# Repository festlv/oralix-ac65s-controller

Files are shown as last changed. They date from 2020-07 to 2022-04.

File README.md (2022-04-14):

# Misc. tools for Gendex Oralix AC65s control

Schematics is a bit stale- initially it was drawn for Arduino Nano, but couldn't find one, 
so a random ESP32 based module was used instead (which was not a bad idea because WiFi provides
better galvanic isolation than shady circuit wired up on perfboard).

ESP32 firmware is however stable- it was initially tested using 12VAC input to allow safe probing
of signals in order to verify the zero crossing detection and pulse timing accuracy.

Description of Gendex Oralix AC tube: https://nucwiki.org/wiki/index.php/Gendex_Oralix_AC

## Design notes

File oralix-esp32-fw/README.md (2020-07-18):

# Triac driver for Gendex Oralix AC65s

This repository contains firmware for ESP32 which controls a triac and allows 
firing X-Ray tube remotely via telnet (providing ultimate galvanic isolation).

Project is built against esp-idf v4.0.x

## Building and installing

    mkdir build && cd build
    cmake ..
    make -j8
    # make menuconfig if want to customize WiFi AP name
    make flash
    
## Usage

0. ESP32 will act as WiFi access point.
1. Connect to WiFi AP (AngryPhotons by default)
2. Use telnet client to connect to 192.168.4.1:23
3. Enter help to see the list of commands (arm, disarm, fire, warmup)

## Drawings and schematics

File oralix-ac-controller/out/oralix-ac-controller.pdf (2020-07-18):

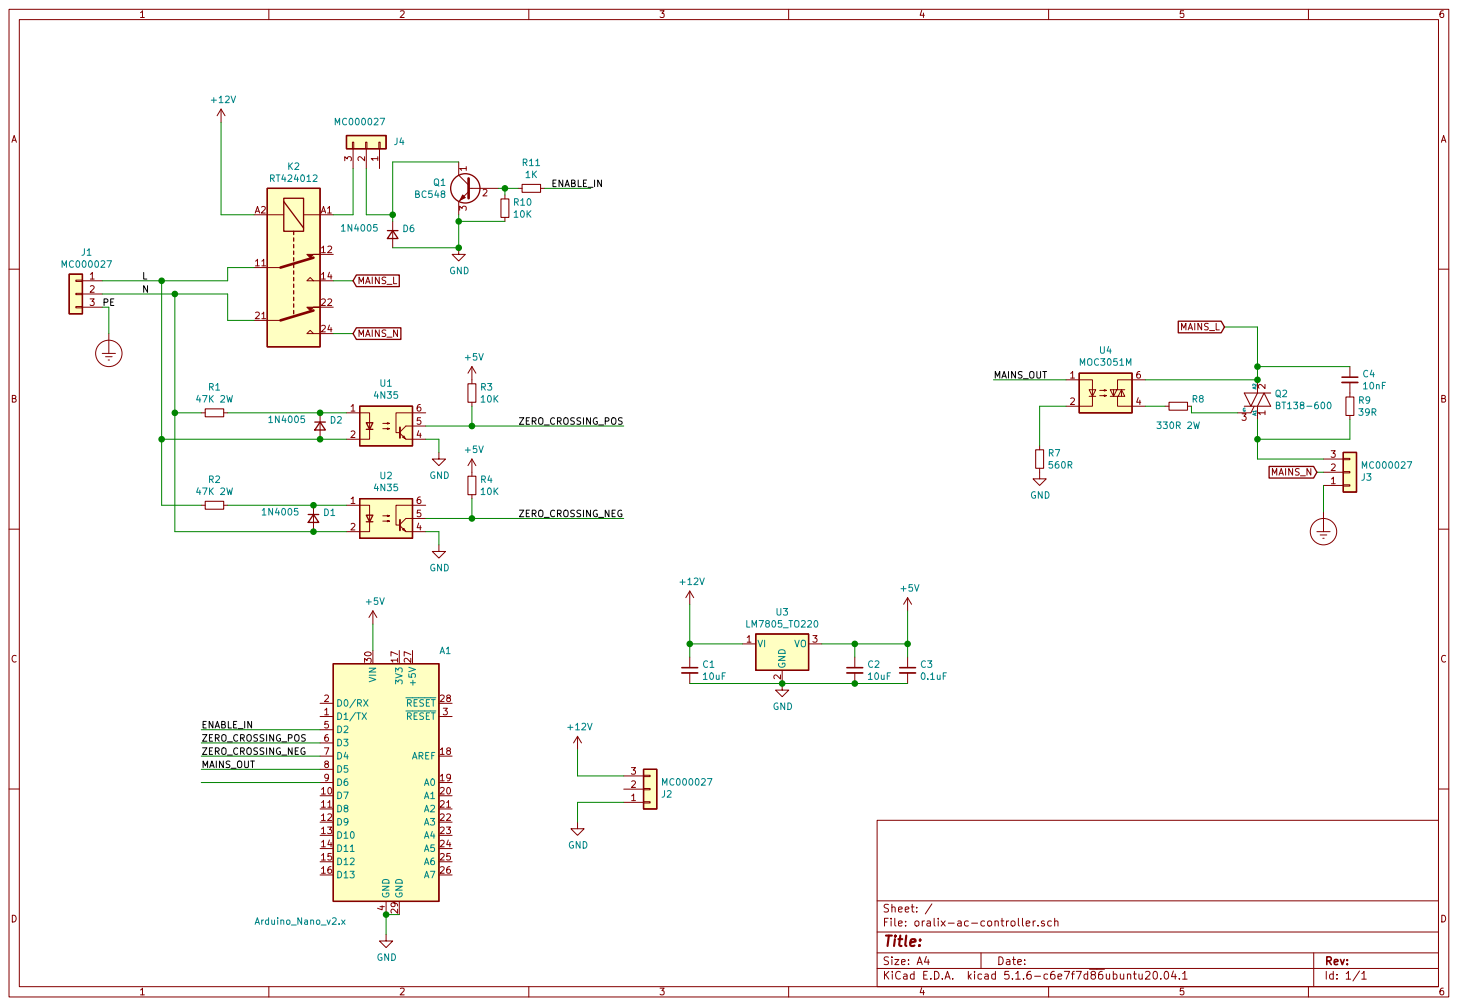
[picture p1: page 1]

Id: 1/1 Title: File: oralix-ac-controller.sch Sheet: /

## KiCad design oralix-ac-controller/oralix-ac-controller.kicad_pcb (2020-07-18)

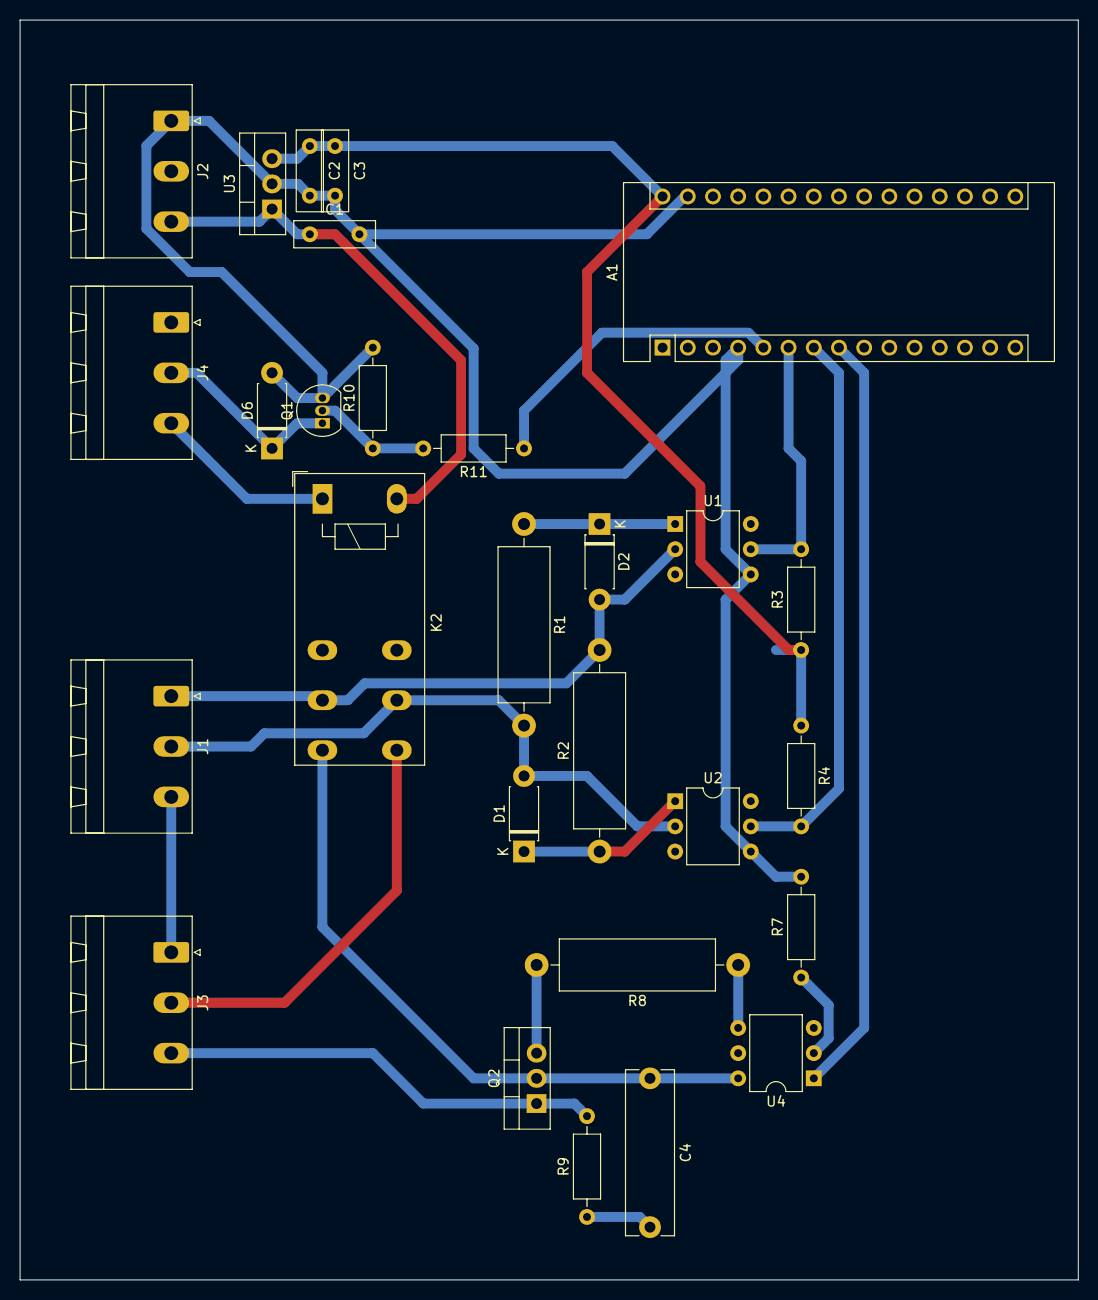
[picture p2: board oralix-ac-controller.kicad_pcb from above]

Board: 2 copper layers, 106.7 x 127.0 mm, 28 parts (0 on the bottom side), 22 nets.

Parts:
A1: Arduino_Nano_v2.x; Arduino_Nano
C1, C2: 10uF; C_Disc_D8.0mm_W2.5mm_P5.00mm
C3: 0.1uF; C_Disc_D8.0mm_W2.5mm_P5.00mm
C4: 10nF; C_Rect_L16.5mm_W4.7mm_P15.00mm_MKT
D1, D2, D6: 1N4005; D_DO-41_SOD81_P7.62mm_Horizontal
J1, J2, J3, J4: MC000027; PhoenixContact_MSTBA_2,5_3-G-5,08_1x03_P5.08mm_Horizontal
K2: RT424012; Relay_DPDT_Schrack-RT2-FormC_RM5mm
Q1: BC548; TO-92_Inline
Q2: BT138-600; TO-220-3_Vertical
R1, R2: 47K 2W; R_Axial_DIN0516_L15.5mm_D5.0mm_P20.32mm_Horizontal
R3, R4, R10: 10K; R_Axial_DIN0207_L6.3mm_D2.5mm_P10.16mm_Horizontal
R7: 560R; R_Axial_DIN0207_L6.3mm_D2.5mm_P10.16mm_Horizontal
R8: 330R 2W; R_Axial_DIN0516_L15.5mm_D5.0mm_P20.32mm_Horizontal
R9: 39R; R_Axial_DIN0207_L6.3mm_D2.5mm_P10.16mm_Horizontal
R11: 1K; R_Axial_DIN0207_L6.3mm_D2.5mm_P10.16mm_Horizontal
U1, U2: 4N35; DIP-6_W7.62mm
U3: LM7805_TO220; TO-220-3_Vertical
U4: MOC3051M; DIP-6_W7.62mm

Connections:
+5V: A1.30, C2.1, C3.1, R3.1, R4.1, U3.3
+12V: C1.1, J2.3, K2.A2, U3.1
/ENABLE_IN: A1.5, R11.1
/L: D2.2, J1.1, K2.11, R2.2, U1.2
/MAINS_OUT: A1.8, U4.1
/N: D1.2, J1.2, K2.21, R1.2, U2.2
/ZERO_CROSSING_NEG: A1.7, R4.2, U2.5
/ZERO_CROSSING_POS: A1.6, R3.2, U1.5
Earth_Protective: J1.3, J3.1
GND: A1.4, A1.29, C1.2, C2.2, C3.2, D6.2, J2.1, Q1.3, R7.2, R10.2, U1.4, U2.4, U3.2
MAINS_L: C4.1, K2.14, Q2.2, U4.6
MAINS_N: J3.2, K2.24
unnamed: C4.2, R9.1
unnamed: D1.1, R2.1, U2.1
unnamed: D2.1, R1.1, U1.1
unnamed: D6.1, J4.2, Q1.1
unnamed: J3.3, Q2.1, R9.2
unnamed: J4.3, K2.A1
unnamed: Q1.2, R10.1, R11.2
unnamed: Q2.3, R8.2
unnamed: R7.1, U4.2
unnamed: R8.1, U4.4

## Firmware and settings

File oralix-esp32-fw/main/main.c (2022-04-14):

/*  WiFi softAP Example

   This example code is in the Public Domain (or CC0 licensed, at your option.)

   Unless required by applicable law or agreed to in writing, this
   software is distributed on an "AS IS" BASIS, WITHOUT WARRANTIES OR
   CONDITIONS OF ANY KIND, either express or implied.
*/
#include <string.h>
#include "freertos/FreeRTOS.h"
#include "freertos/task.h"
#include "driver/uart.h"
#include "esp_system.h"
#include "esp_wifi.h"
#include "esp_event.h"
#include "esp_log.h"
#include "nvs_flash.h"
#include "telnet.h"
#include "lwip/err.h"
#include "lwip/sys.h"
#include "driver.h"
/* The examples use WiFi configuration that you can set via project configuration menu.

   If you'd rather not, just change the below entries to strings with
   the config you want - ie #define EXAMPLE_WIFI_SSID "mywifissid"
*/
#define EXAMPLE_ESP_WIFI_SSID      CONFIG_ESP_WIFI_SSID
#define EXAMPLE_ESP_WIFI_PASS      CONFIG_ESP_WIFI_PASSWORD
#define EXAMPLE_MAX_STA_CONN       CONFIG_ESP_MAX_STA_CONN

static const char *TAG = "wifi";

static void wifi_event_handler(void* arg, esp_event_base_t event_base,
                                    int32_t event_id, void* event_data)
{
    if (event_id == WIFI_EVENT_AP_STACONNECTED) {
        wifi_event_ap_staconnected_t* event = (wifi_event_ap_staconnected_t*) event_data;
        ESP_LOGI(TAG, "station "MACSTR" join, AID=%d",
                 MAC2STR(event->mac), event->aid);
    } else if (event_id == WIFI_EVENT_AP_STADISCONNECTED) {
        wifi_event_ap_stadisconnected_t* event = (wifi_event_ap_stadisconnected_t*) event_data;
        ESP_LOGI(TAG, "station "MACSTR" leave, AID=%d",
                 MAC2STR(event->mac), event->aid);
    }
}

static char tag[] = "xray";


#define STATIC_RESPOND(x) (respond_func((uint8_t*)x, strlen(x)))
#define RESPOND(x, y) (respond_func(x, y))

static void process_line(uint8_t *buffer, size_t size, void (*respond_func)(uint8_t*, size_t)) {
	ESP_LOGD(tag, "received: %.*s", size, buffer);

    if (strncmp((char*)buffer, "help", 4) == 0) {
        STATIC_RESPOND("Welcome brave warrior!\n");
        STATIC_RESPOND("Commands: \n");
        STATIC_RESPOND("status: driver status\n");
        STATIC_RESPOND("arm: arms the device (enables input relay)\n");
        STATIC_RESPOND("disarm: disarms\n");
        STATIC_RESPOND("warmup: warms up the tube (sends 6 pulses)\n");
        STATIC_RESPOND("fire <ms>: warms up the tube and performs an exposure of <ms> duration\n");
        STATIC_RESPOND("fire_nowarmup <ms>: fires tube for <ms> without warmup (CAUTION!)\n");
        STATIC_RESPOND("\n");
    }

    if (strncmp((char*)buffer, "status", 6) == 0) {
        char buf[256];
        uint32_t len = driver_get_status(buf, sizeof(buf));
        RESPOND((uint8_t *)buf, len);
    }

    if (strncmp((char*)buffer, "arm", 3) == 0) {
	    if (driver_arm()) {
	        STATIC_RESPOND("OK:armed\n");
	    } else {
	        STATIC_RESPOND("FAIL:failed to arm\n");
	    }
	}
    if (strncmp((char*)buffer, "disarm", 6) == 0) {
        if (driver_disarm()) {
            STATIC_RESPOND("OK:disarmed\n");
        } else {
            STATIC_RESPOND("FAIL:failed to disarm, run!\n");
        }
    }
    if (strncmp((char*)buffer, "warmup", 6) == 0) {
        if (driver_warmup()) {
            STATIC_RESPOND("OK:started warmup\n");
        } else {
            STATIC_RESPOND("FAIL:failed to start warmup!\n");
        }
    }
    if (strncmp((char*)buffer, "fire_nowarmup", 13) == 0) {
        int time_ms;
        if (sscanf((char*)(buffer + 14), "%d", &time_ms) == 1) {
            if (time_ms < 0 || time_ms > 3000) {
                STATIC_RESPOND("FAIL:Dave, I'm afraid I can't do that.\n");
            } else {
                if (driver_fire_time_nowarmup(time_ms)) {
                    STATIC_RESPOND("OK:firing!\n");
                } else {
                    STATIC_RESPOND("FAIL:failed to fire!\n");
                }
            }
        } else {
            STATIC_RESPOND("FAIL:failed to parse time!\n");
        }
    } else if (strncmp((char*)buffer, "fire", 4) == 0) {
        int time_ms;
        if (sscanf((char*)(buffer + 5), "%d", &time_ms) == 1) {
            if (time_ms < 0 || time_ms > 3000) {
                STATIC_RESPOND("FAIL:Dave, I'm afraid I can't do that.\n");
            } else {
                if (driver_fire_time(time_ms)) {
                    STATIC_RESPOND("OK:firing!\n");
                } else {
                    STATIC_RESPOND("FAIL:failed to fire!\n");
                }
            }
        } else {
            STATIC_RESPOND("FAIL:failed to parse time!\n");
        }
    }
}

static void telnetRecvData(uint8_t *buffer, size_t size) {
    process_line(buffer, size, &telnet_esp32_sendData);
}

static void telnetTask(void *data) {
	ESP_LOGD(tag, ">> telnetTask");
	telnet_esp32_listenForClients(telnetRecvData);
	ESP_LOGD(tag, "<< telnetTask");
	vTaskDelete(NULL);
}


void wifi_init_softap()
{
    tcpip_adapter_init();
    ESP_ERROR_CHECK(esp_event_loop_create_default());

    wifi_init_config_t cfg = WIFI_INIT_CONFIG_DEFAULT();
    ESP_ERROR_CHECK(esp_wifi_init(&cfg));

    ESP_ERROR_CHECK(esp_event_handler_register(WIFI_EVENT, ESP_EVENT_ANY_ID, &wifi_event_handler, NULL));

    wifi_config_t wifi_config = {
        .ap = {
            .ssid = EXAMPLE_ESP_WIFI_SSID,
            .ssid_len = strlen(EXAMPLE_ESP_WIFI_SSID),
            .password = EXAMPLE_ESP_WIFI_PASS,
            .max_connection = EXAMPLE_MAX_STA_CONN,
            .authmode = WIFI_AUTH_WPA_WPA2_PSK
        },
    };
    if (strlen(EXAMPLE_ESP_WIFI_PASS) == 0) {
        wifi_config.ap.authmode = WIFI_AUTH_OPEN;
    }

    ESP_ERROR_CHECK(esp_wifi_set_mode(WIFI_MODE_AP));
    ESP_ERROR_CHECK(esp_wifi_set_config(ESP_IF_WIFI_AP, &wifi_config));
    ESP_ERROR_CHECK(esp_wifi_start());

    ESP_LOGI(TAG, "wifi_init_softap finished. SSID:%s password:%s",
             EXAMPLE_ESP_WIFI_SSID, EXAMPLE_ESP_WIFI_PASS);
}

static void uartRespond(uint8_t* data, size_t len) {
    uart_write_bytes(UART_NUM_2, (const char*)data, len);
}
static void uartTask(void* data) {
    ESP_LOGD(tag, ">> uartTask");
    const uart_port_t uart_num = UART_NUM_2;
    uart_config_t uart_config = {
        .baud_rate = 115200,
        .data_bits = UART_DATA_8_BITS,
        .parity = UART_PARITY_DISABLE,
        .stop_bits = UART_STOP_BITS_1,
        .flow_ctrl = UART_HW_FLOWCTRL_DISABLE,
        .rx_flow_ctrl_thresh = 122,
    };
    // Configure UART parameters
    ESP_ERROR_CHECK(uart_param_config(uart_num, &uart_config));
    ESP_ERROR_CHECK(uart_set_pin(UART_NUM_2, 27, 26, UART_PIN_NO_CHANGE, UART_PIN_NO_CHANGE));

    // Setup UART buffered IO with event queue
    const int uart_buffer_size = (1024 * 2);
    QueueHandle_t uart_queue;
    // Install UART driver using an event queue here
    ESP_ERROR_CHECK(uart_driver_install(UART_NUM_2, uart_buffer_size, \
                                            uart_buffer_size, 10, &uart_queue, 0));

    uint8_t rx_buffer[512];
    int rx_buffer_idx=0;

    while (true) {
        int length = 0;
        ESP_ERROR_CHECK(uart_get_buffered_data_len(UART_NUM_2, (size_t*)&length));
        if (length > 0) {
            length = uart_read_bytes(UART_NUM_2, rx_buffer + rx_buffer_idx, length, 100);
            rx_buffer_idx += length;

            //check for \n in the received data
            for (int i=0; i < rx_buffer_idx; i++) {
                if (rx_buffer[i] == '\n') {
                    process_line(rx_buffer, i, &uartRespond);
                    rx_buffer_idx = 0;
                    break;
                }
            }
        }
        vTaskDelay(1);
    }
}
void app_main()
{
    //Initialize NVS
    esp_err_t ret = nvs_flash_init();
    if (ret == ESP_ERR_NVS_NO_FREE_PAGES || ret == ESP_ERR_NVS_NEW_VERSION_FOUND) {
      ESP_ERROR_CHECK(nvs_flash_erase());
      ret = nvs_flash_init();
    }
    ESP_ERROR_CHECK(ret);

    ESP_LOGI(TAG, "ESP_WIFI_MODE_AP");
    wifi_init_softap();
    xTaskCreatePinnedToCore(&telnetTask, "telnetTask", 8048, NULL, 5, NULL, 0);
    xTaskCreatePinnedToCore(&uartTask, "uartTask", 8048, NULL, 5, NULL, 0);
    
    driver_init();
}

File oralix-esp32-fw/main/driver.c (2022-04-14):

//
// Created by reinis on 18.07.20.
//
#include "driver.h"
#include <memory.h>
#include <freertos/FreeRTOS.h>
#include <freertos/task.h>
#include <driver/gpio.h>
#include <driver/timer.h>
#define ARM_RELAY_GPIO 21
#define FIRE_TRIAC_GPIO 19
#define STATUS_LED_GPIO 23

//DUTY cycle of tube (if firing for 100ms, need to wait 100ms * 30 before firing again
#define TUBE_DUTY_CYCLE 30
#define TUBE_MIN_COOLDOWN_US (30*1000*1000)

#define ZCD_POS_GPIO 16
#define ZCD_NEG_GPIO 17

//length of mains half-cycle at 50Hz
#define PULSE_DURATION_US 20000
#define NUM_WARMUP_PULSES 6
inline void delay_ms(uint32_t ms) {
    vTaskDelay(ms / portTICK_PERIOD_MS);
}
typedef struct {
    uint32_t zcd_num_pos_rising_pulses;
    uint64_t zcd_pos_rising_pulse_us;
    uint32_t zcd_num_neg_rising_pulses;
    uint64_t zcd_neg_rising_pulse_us;

    uint64_t fire_start_us;
    uint64_t fire_end_us;

    bool fire_on_zcd;
    bool is_firing;
    bool armed;
    uint32_t fire_duration_us;
    uint32_t fire_actual_duration_us;
} timing_state_t;

static volatile timing_state_t state;

esp_timer_handle_t fire_stop_timer;

/**
 * Checks if it's safe to fire the tube (duty cycle not exceeded)
 * @return
 */
static bool driver_check_duty_cycle() {
    uint64_t time_us = esp_timer_get_time();
    if (state.fire_actual_duration_us == 0)
        return true;

    uint64_t cool_time = time_us - state.fire_end_us;
    if ((cool_time / state.fire_actual_duration_us) < TUBE_DUTY_CYCLE) {
        //duty cycle exceeded
        return false;
    }

    if (cool_time < TUBE_MIN_COOLDOWN_US)
        return false;

    return true;
}
static void driver_task(void* arg) {
    for (int i = 0; i < 5; i++) {
        gpio_set_level(STATUS_LED_GPIO, 1);
        delay_ms(100);
        gpio_set_level(STATUS_LED_GPIO, 0);
        delay_ms(100);
    }

    while (1) {
        gpio_set_level(STATUS_LED_GPIO, 1);
        delay_ms(1000);
        gpio_set_level(STATUS_LED_GPIO, 0);
        delay_ms(1000);
    }
}

static void driver_int_zcd_pos(void* arg) {
    uint64_t time_us = esp_timer_get_time();
    //debounce
    if ((time_us - state.zcd_pos_rising_pulse_us) > 5000) {
        state.zcd_num_pos_rising_pulses++;
        state.zcd_pos_rising_pulse_us = time_us;

        if (state.fire_on_zcd) {
            state.fire_start_us = time_us;
            state.fire_end_us = time_us + state.fire_duration_us;
            state.fire_on_zcd = false;
            state.fire_actual_duration_us = 0;
            gpio_set_level(FIRE_TRIAC_GPIO, 1);
            esp_timer_start_once(fire_stop_timer, state.fire_duration_us);
            state.is_firing = true;
        }

    }
}

static void driver_int_zcd_neg(void* arg) {
    uint64_t time_us = esp_timer_get_time();
    //debounce
    if ((time_us - state.zcd_neg_rising_pulse_us) > 5000) {
        state.zcd_num_neg_rising_pulses++;
        state.zcd_neg_rising_pulse_us = time_us;
    }
}

static void driver_stop_fire(void* arg) {

    gpio_set_level(FIRE_TRIAC_GPIO, 0);
    uint64_t time_us = esp_timer_get_time();
    state.is_firing = false;
    state.fire_actual_duration_us = time_us - state.fire_start_us;
}

void driver_init()
{
    memset(&state, 0, sizeof(state));
    gpio_pad_select_gpio(ARM_RELAY_GPIO);
    gpio_pad_select_gpio(FIRE_TRIAC_GPIO);
    gpio_pad_select_gpio(STATUS_LED_GPIO);
    gpio_pad_select_gpio(ZCD_POS_GPIO);
    gpio_pad_select_gpio(ZCD_NEG_GPIO);

    /* Set the GPIO as a push/pull output */
    gpio_set_level(FIRE_TRIAC_GPIO, 0);
    gpio_set_direction(FIRE_TRIAC_GPIO, GPIO_MODE_OUTPUT);

    gpio_set_level(ARM_RELAY_GPIO, 0);
    gpio_set_direction(ARM_RELAY_GPIO, GPIO_MODE_OUTPUT);

    gpio_set_level(STATUS_LED_GPIO, 0);
    gpio_set_direction(STATUS_LED_GPIO, GPIO_MODE_OUTPUT);

    /* Set GPIO as inputs with pull-ups (in case the ones on board unsolder themselves */
    gpio_set_direction(ZCD_POS_GPIO, GPIO_MODE_INPUT);
    gpio_pullup_en(ZCD_POS_GPIO);
    gpio_set_direction(ZCD_NEG_GPIO, GPIO_MODE_INPUT);
    gpio_pullup_en(ZCD_NEG_GPIO);
    esp_timer_create_args_t args;
    args.name = "fire-stop-timer";
    args.arg = NULL;
    args.dispatch_method = ESP_TIMER_TASK;
    args.callback = &driver_stop_fire;
    esp_timer_create(&args, &fire_stop_timer);

    gpio_install_isr_service(0);
    gpio_isr_handler_add(ZCD_POS_GPIO, &driver_int_zcd_pos, NULL);
    gpio_set_intr_type(ZCD_POS_GPIO, GPIO_INTR_POSEDGE);
    gpio_isr_handler_add(ZCD_NEG_GPIO, &driver_int_zcd_neg, NULL);
    gpio_set_intr_type(ZCD_NEG_GPIO, GPIO_INTR_POSEDGE);
    xTaskCreatePinnedToCore(&driver_task, "xray", 8048, NULL, 5, NULL, 1);
}

bool driver_arm() {
    gpio_set_level(ARM_RELAY_GPIO, 1);
    state.armed = true;
    return true;
}

bool driver_disarm() {
    gpio_set_level(ARM_RELAY_GPIO, 0);
    state.armed = false;
    return true;
}

uint32_t driver_get_status(char *outstr, uint32_t outstrlen) {
    return snprintf(outstr, outstrlen, "armed: %d\nzcd_pos: %d\nzcd_neg: %d\nis_firing: %d\nfire_actual_duration_us: %d\n",
            state.armed,
            state.zcd_num_pos_rising_pulses,
            state.zcd_num_neg_rising_pulses,
            state.is_firing,
            state.fire_actual_duration_us
            );
}

bool driver_warmup() {
    if (driver_check_duty_cycle() && state.armed) {
        state.fire_duration_us = NUM_WARMUP_PULSES * PULSE_DURATION_US;
        state.fire_on_zcd = true;
        return true;
    }
    return false;
}

bool driver_fire_time(uint32_t milliseconds) {
    if (driver_check_duty_cycle() && state.armed) {
        //round down to nearest half-cycle length
        state.fire_duration_us = (milliseconds * 1000 + NUM_WARMUP_PULSES * PULSE_DURATION_US) / PULSE_DURATION_US * PULSE_DURATION_US;
        state.fire_on_zcd = true;
        return true;
    }
    return false;
}

bool driver_fire_time_nowarmup(uint32_t milliseconds) {
    if (driver_check_duty_cycle() && state.armed) {
        state.fire_duration_us = (milliseconds * 1000);
        state.fire_on_zcd = true;
        return true;
    }
    return false;
}

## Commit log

2020-07-18 Added xray tube controller hardware source (in kicad)
    [oralix-ac-controller.kicad_pcb, oralix-ac-controller.sch]
2022-04-14 Add UART as command channel
2022-04-14 Prefix responses with OK/FAIL to make automated parsing easier
    [main.c]
